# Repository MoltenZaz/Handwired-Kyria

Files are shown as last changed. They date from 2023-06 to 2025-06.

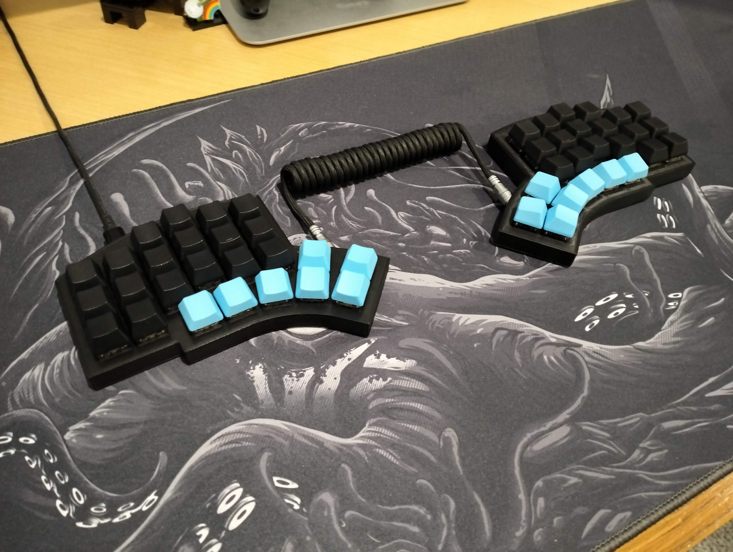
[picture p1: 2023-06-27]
Photos/IMG20230628023153.jpg

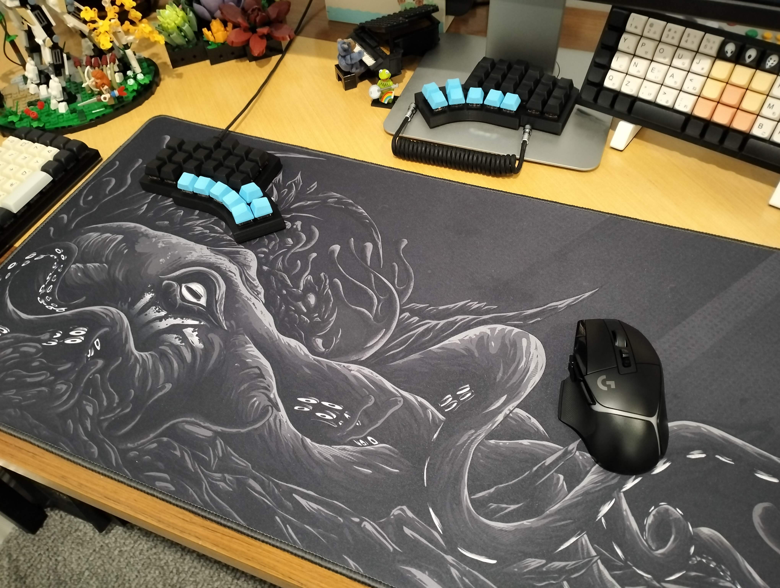
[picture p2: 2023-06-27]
Photos/IMG20230628023544.jpg

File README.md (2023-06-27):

# Handwired-Kyria
A handwired version of the kyria keyboard by splitkb.com

Needed parts:
- 3D printed case (mirror provided stls for right side)
- 50x keyboard switches of your choice (I used durock L7 67g)
- 50x 1N4148 diodes
- 2x 4 pin XS6 mini Aviation plug & socket (https://www.aliexpress.com/item/1005004089293971.html)
- 2x Waveshare RP2040-Zero Microcontrollers (https://core-electronics.com.au/rp2040-zero-a-pico-like-mcu-board-based-on-raspberry-pi-mcu-rp2040-mini-ver-1.html)
- wire for connecting switches to microcontrollers, I used stranded alarm wire (https://www.jaycar.com.au/4-core-alarm-cable-sold-per-metre/p/WB1590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)
- 4 core cable for connecting both halves, I used the same alarm wire mentioned previously
- Keycaps of your choice, I used blank pbt oem.
- 30x m2 6mm heatset inserts (https://www.aliexpress.com/item/1005005220632314.html)
- 30x m2 6mm countersunk screws (https://www.aliexpress.com/item/1005003986879500.html)

Optional but highly recommended:
- 50x hotswap sockets (https://www.aliexpress.com/item/1005004290562374.html)
- paracord for sleeving the cable
- magnetic usb c cable (https://www.aliexpress.com/item/1005005402419615.html)
- heatshrink
- rubber feet (https://www.aliexpress.com/item/1005003412490420.html)

Notes for building:
- if using hotswap sockets solder on the bottom for the switches under the microcontroller! the tolerance is tight!
- put electrical tape on the switches under the microcontoller
- the xs6 connector is used to wire the microcontrollers together, you need to wire GP0-GP0, GP1-GP1, 3.3v-3.3v, Ground-Ground. Make sure you are wiring it correctly and check with a multimeter, make sure that they aren't shorting to each other as it is quite a small connector.
- the cable and paracord that I used was very tight in the connector, to make it fit easier I used a pair of scissors to scrape the cable rubber sleeving and make it as thin as possible without removing the sleeving
- I found it difficult to solder the sx6 connector on the cable side because of its size, take your time and try to put heatshrink around each solder point to avoid accidental shorts
- it is better to use a more flexible wire so that it's easier to jam the microcontroller into it's slot, originally I used solid core wire and it was difficult to get the microcontroller in
- print the test prints to check tolerances and your print settings before printing the full case
- I used angled tip pliers to put the nut on the xs6 socket, I didn't want to make that section of the case any thinner because when I was testing with white filament it would have become transparent
- The reason that I used the xs6 connector is that trrs is not hotplug safe and the xs6 mini was the smallest suitable connector I could find and as a bonus it's a pretty cool connector

Firmware notes:
- I have included my qmk files, my keymap is probably more complicated than you want I recommend looking through my layout then either modifiying it to your liking or making your own
- I'm using EE_HANDS to determine the side of the split so when flashing select the uf2-split-left bootloader for left and uf2-split-right for right. For example to flash the keyboard I use the command "qmk flash -kb handwired/kyria_mt -km mitchell -bl uf2-split-left" and "qmk flash -kb handwired/kyria_mt -km mitchell -bl uf2-split-right" in qmk msys

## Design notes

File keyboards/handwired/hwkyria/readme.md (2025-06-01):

# hwkyria

hwkyria

*A short description of the keyboard/project*

* Keyboard Maintainer: [MoltenZaz](https://github.com/MoltenZaz)
* Hardware Supported: *The PCBs, controllers supported*
* Hardware Availability: *Links to where you can find this hardware*

Make example for this keyboard (after setting up your build environment):

    make hwkyria:default

Flashing example for this keyboard:

    make hwkyria:default:flash

See the [build environment setup](https://docs.qmk.fm/#/getting_started_build_tools) and the [make instructions](https://docs.qmk.fm/#/getting_started_make_guide) for more information. Brand new to QMK? Start with our [Complete Newbs Guide](https://docs.qmk.fm/#/newbs).

## Bootloader

Enter the bootloader in 3 ways:

* **Bootmagic reset**: Hold down the key at (0,0) in the matrix (usually the top left key or Escape) and plug in the keyboard
* **Physical reset button**: Briefly press the button on the back of the PCB - some may have pads you must short instead
* **Keycode in layout**: Press the key mapped to `QK_BOOT` if it is available

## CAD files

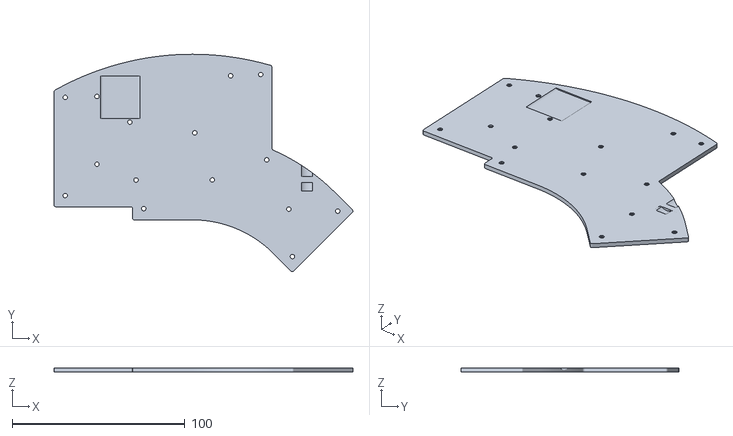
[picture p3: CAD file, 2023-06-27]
Case STLs/case_bottom_left.stl
172.9 x 125.8 x 2.30

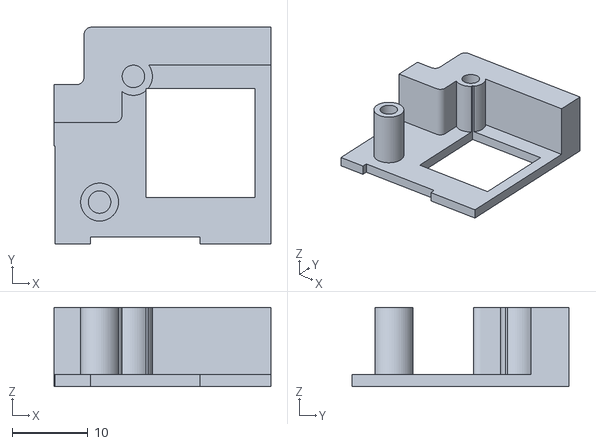
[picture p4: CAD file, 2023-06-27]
Case STLs/Test Files/standoff_tolerance_test.stl
28.6 x 28.5 x 10.4

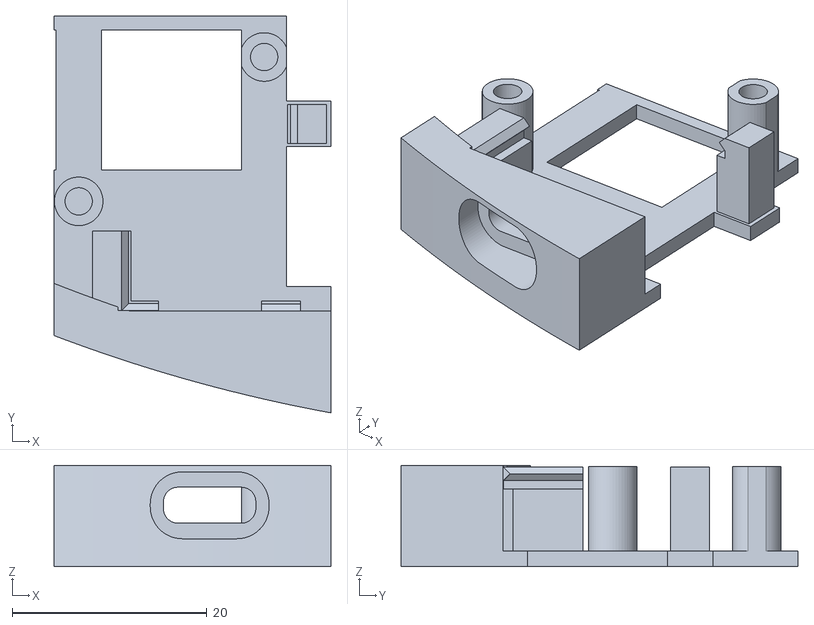
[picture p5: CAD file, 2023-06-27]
Case STLs/Test Files/microcontroller_tolerance_test.stl
28.5 x 40.8 x 10.4

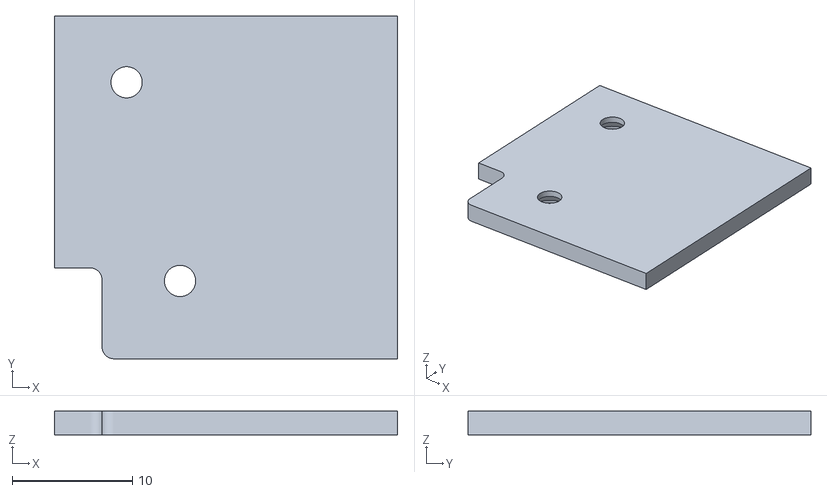
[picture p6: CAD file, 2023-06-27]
Case STLs/Test Files/standoff_bottom_tolerance_test.stl
28.6 x 28.5 x 1.98

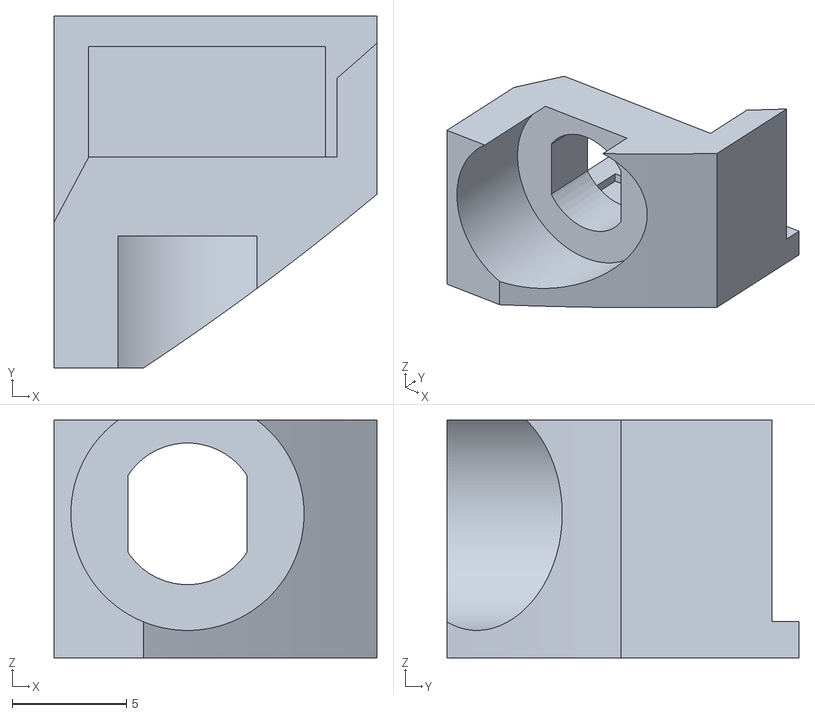
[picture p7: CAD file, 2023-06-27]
Case STLs/Test Files/xs6_tolerance_test.stl
14.1 x 15.4 x 10.4

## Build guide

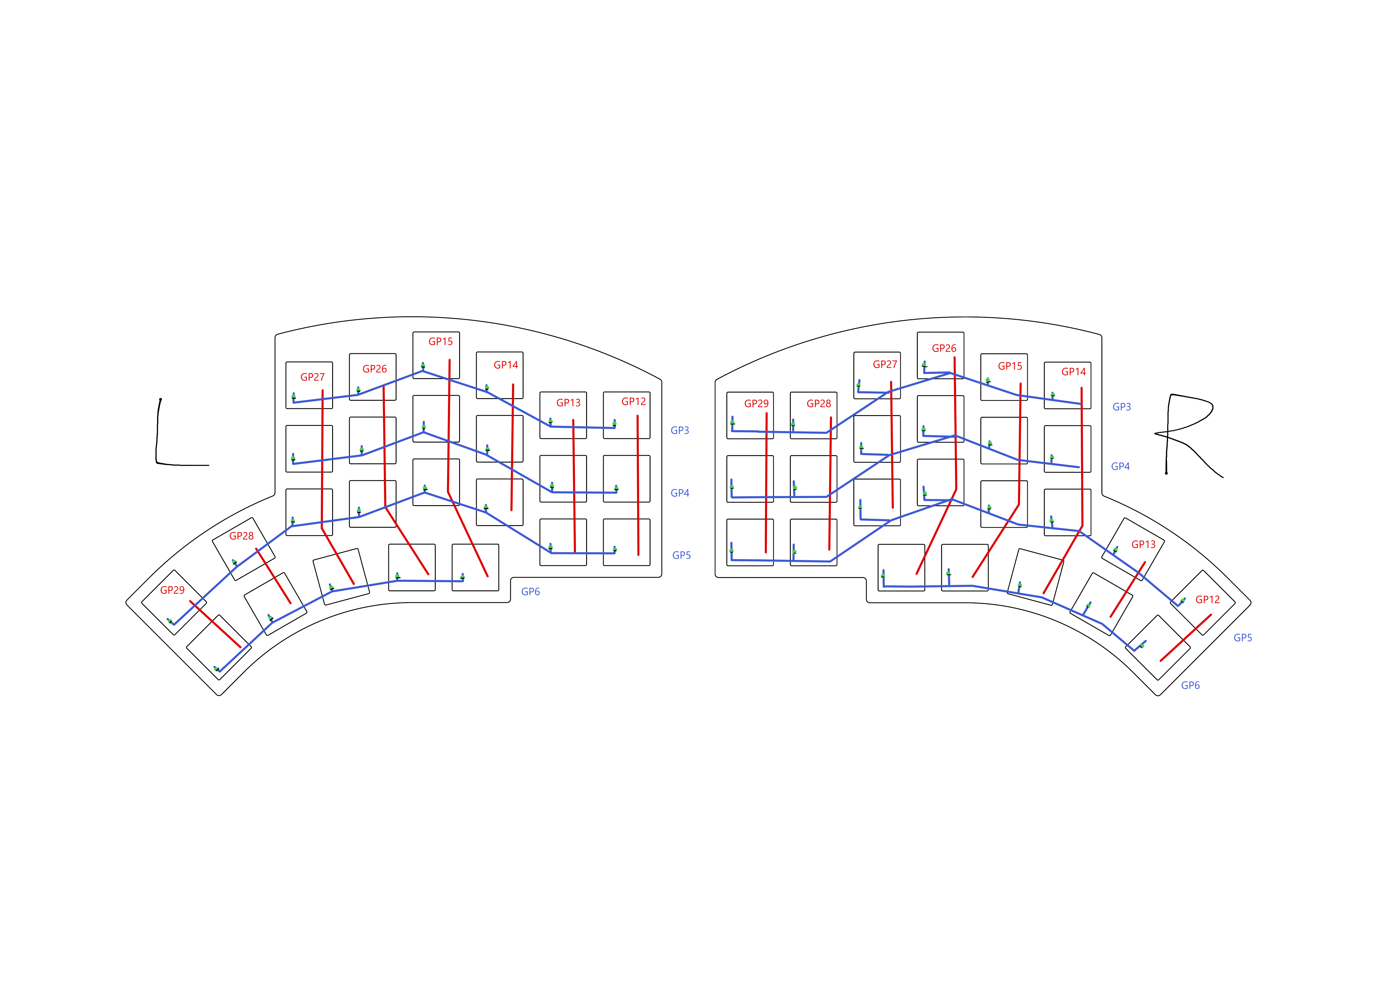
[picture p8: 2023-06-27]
wiring diagram.png

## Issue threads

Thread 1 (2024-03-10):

Qmk doesn't let me flash the Waveshare RP2040-Zero Microcontroller

mabra129, 2024-03-10:
I followed your guide on building the board and bought exactly the parts you mentioned. After finishing the left half of the keyboard, I wanted to test the keys by starting out using your keymap. When I opened qmk software and connected the controller to the pc while pressing the boot button (on the controller), the software detected the controller "USB device connected (NO DRIVER):  RP2 Boot (2E8A:0003:0100)" but it didn't let me flash the controller. It's not in correlation to your code, but could you maybe share how you got your microcontroller flashed for the first time?

MoltenZaz, 2024-03-11:
The first time I physically pressed the reset button on the microcontroller by removing the switch directly above it and poking the button with a skewer, either double press or press and hold for a couple of seconds. Or you can press and hold the boot switch while connecting the usb cable. You'll know it's in boot mode if it appears like a usb flash drive in file explorer named RPI-RP2 or something like that.

I don't recall seeing the error message you mentioned but the wording of it makes me think your microcontroller isn't in boot mode.

You could try compiling the firmware in qmk msys and rather than flashing directly enter boot mode on the microcontroller then drag and drop the firmware uf2 file into the usb storage device that appears when the microcontroller is in boot mode.

Make sure your keymap has a QK_BOOT key so that you can change the keymap in the future without having to press the button on the microcontroller. i have mine a few layers deep to avoid accidentally pressing it.

MoltenZaz, 2024-03-11:
You could try this uf2 file, make sure to only put the uf2 file on the microcontroller, not the zip.
[mkyria_mitchell.zip](https://github.com/MoltenZaz/Handwired-Kyria/files/14552357/mkyria_mitchell.zip)

mabra129, 2024-03-11:
thank you I will try this

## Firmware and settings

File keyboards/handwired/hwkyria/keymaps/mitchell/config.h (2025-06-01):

/* Copyright 2022 Thomas Baart <thomas@splitkb.com>
 *
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
 * You should have received a copy of the GNU General Public License
 * along with this program.  If not, see <http://www.gnu.org/licenses/>.
 */

#pragma once

// place overrides here
#define USB_POLLING_INTERVAL_MS 1
#define QMK_KEYS_PER_SCAN 24
#define FORCE_NKRO
// #define TAPPING_TOGGLE 1
#define LCPO_KEYS KC_LCTL, KC_LSFT, KC_LBRC
#define RCPC_KEYS KC_RCTL, KC_RSFT, KC_RBRC
#define LAPO_KEYS KC_LALT, KC_TRNS, KC_LBRC
#define RAPC_KEYS KC_RALT, KC_TRNS, KC_RBRC
#define LAYER_STATE_32BIT

#define UNICODE_SELECTED_MODES UNICODE_MODE_WINDOWS, UNICODE_MODE_LINUX
#define UNICODE_KEY_WINC KC_PAUSE

#define TAPPING_TERM 200
#define QUICK_TAP_TERM 0
// #define PERMISSIVE_HOLD
#define HOLD_ON_OTHER_KEY_PRESS
// #define HOLD_ON_OTHER_KEY_PRESS_PER_KEY
#define TAP_CODE_DELAY 30

#define TRI_LAYER_LOWER_LAYER 3
#define TRI_LAYER_UPPER_LAYER 5
#define TRI_LAYER_ADJUST_LAYER 6

// #define MOUSEKEY_INTERVAL 16

// #define MOUSEKEY_DELAY 0

// #define MOUSEKEY_TIME_TO_MAX 60

// #define MOUSEKEY_MAX_SPEED 5

// #define MOUSEKEY_WHEEL_DELAY 0

// #define MK_3_SPEED
// #define MK_MOMENTARY_ACCEL

// #undef MOUSEKEY_DELAY
// #define MOUSEKEY_DELAY          0
// #undef MOUSEKEY_INTERVAL
// #define MOUSEKEY_INTERVAL       16
// #undef MOUSEKEY_WHEEL_DELAY
// #define MOUSEKEY_WHEEL_DELAY    0
// #undef MOUSEKEY_MAX_SPEED
// #define MOUSEKEY_MAX_SPEED      6
// #undef MOUSEKEY_TIME_TO_MAX
// #define MOUSEKEY_TIME_TO_MAX    64

#define MK_KINETIC_SPEED
#define MOUSEKEY_DELAY							5
#define MOUSEKEY_INTERVAL						8
#define MOUSEKEY_MOVE_DELTA						16
#define MOUSEKEY_INITIAL_SPEED					100
#define MOUSEKEY_BASE_SPEED						5000
#define MOUSEKEY_DECELERATED_SPEED				400
#define MOUSEKEY_ACCELERATED_SPEED				3000
#define MOUSEKEY_WHEEL_INITIAL_MOVEMENTS		8
#define MOUSEKEY_WHEEL_BASE_MOVEMENTS			16
#define MOUSEKEY_WHEEL_ACCELERATED_MOVEMENTS	48
#define MOUSEKEY_WHEEL_DECELERATED_MOVEMENTS	8

// #define BOTH_SHIFTS_TURNS_ON_CAPS_WORD
// #define CAPS_WORD_INVERT_ON_SHIFT
// #define CAPS_WORD_IDLE_TIMEOUT 5000

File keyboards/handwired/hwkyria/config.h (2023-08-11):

#ifndef CONFIG_H
#define CONFIG_H

//#include "config_common.h"
#pragma once

#define RAW_USAGE_PAGE 0xFF60
#define RAW_USAGE_ID 0x61

/* configure split */
#define EE_HANDS

#define SERIAL_PIO_USE_PIO1 // Force the usage of PIO1 peripheral, by default the Serial implementation uses the PIO0 peripheral
#define SERIAL_USART_FULL_DUPLEX   // Enable full duplex operation mode.
#define SERIAL_USART_RX_PIN GP0    // USART RX pin
#define SERIAL_USART_TX_PIN GP1     // USART TX pin
#define SERIAL_USART_PIN_SWAP      // Swap TX and RX pins if keyboard is master halve. (Only available on some MCUs)

/* key matrix size */
#define MATRIX_ROWS 8
#define MATRIX_COLS 8

/* Set 0 if debouncing isn't needed */
#define DEBOUNCE 5

/* Locking resynchronize hack */
#define LOCKING_RESYNC_ENABLE

#define RP2040_BOOTLOADER_DOUBLE_TAP_RESET // Activates the double-tap behavior
#define RP2040_BOOTLOADER_DOUBLE_TAP_RESET_TIMEOUT 200U // Timeout window in ms in which the double tap can occur.
#define RP2040_BOOTLOADER_DOUBLE_TAP_RESET_LED GP16 // Specify a optional status led by GPIO number which blinks when entering the bootloader

#endif

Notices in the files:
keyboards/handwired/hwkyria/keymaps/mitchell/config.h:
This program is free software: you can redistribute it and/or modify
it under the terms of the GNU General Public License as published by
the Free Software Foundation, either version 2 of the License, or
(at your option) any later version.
